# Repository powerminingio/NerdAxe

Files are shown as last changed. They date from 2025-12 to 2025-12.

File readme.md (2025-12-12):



# The Nerdaxe
NerdAxe is a fork from bitaxe with fullcolor display graphics. NerdAxe is indented to be an upgrade board for these who have a NerdMiner and would like to have more powerful mining features without losing the NerdMiner essence. That's why NerdAxe is currently controlled by the common board used on Nerdminer project called TTGO-TDisplayS3.

Currently exists two variants sepparated in two branches:
- **Nerdaxe Gamma**: 1,2Th with a single chip BM1370. [Nerdaxe Gamma](https://github.com/BitMaker-hub/NerdAxe/tree/gamma-1%2C2Ths)
- **Nerdaxe Ultra**: 0,5Th with a single chip BM1366. [Nerdaxe Ultra](https://github.com/BitMaker-hub/NerdAxe/tree/ultra-500Ghs)

The following fork could not be possible without the previous work of @skot, @ben & bitaxe devs. [Check bitaxe project](https://bitaxe.org)

Upgrade your NerdMiner experience throught this addon board and start playing with ASICs

NerdAxeUltra design

## Goals
- **Plug&Play**: your NerdMiner board and convert it into a NerdAxe.
- **Standalone**: can mine directly to your pool over WiFi. No External computer needed.
- **Embedded**: low cost, low maintenance, high availability, high reliability, low power.
- **ASIC**: working with most efficient ASIC chips from Bitmain - BM1370.
- **Versatile**: solo/pool mining, autotune power/heat/efficiency.
- **Open Source**: All design files are provided.

## Features
- **TTGO-TDisplay** ESP32s3 wifi microcontroller display board
- **Multiple Screens** to allow you see all the miner stats 
- **TI TPS546D** buck regulator steps down the 5V input to power the BM1370
- **Microchip EMC2101** PWM controls the fan and monitors tach output. Measuring internal die temp isn't working.

## Additional Features added by Powermining
- **Two fan connectors** - no need for splitter cable if you use secondary fan.
- **Threaded heatsink mounting holes** PCB with M3 threads for firm heatsink mounting
- **OG matching heatsink bolt pattern** no headache with non fitting standard bolt patterns! We keep the Nerdaxe standard 41.49x41.35

## Software & Firmware
Nerdaxe firmware was forked from original ESP-Miner version and adapted to use TTGO board and LVGL as graphic interface lib. 
Check it here -> [ESP-Miner Nerdaxe version](https://github.com/BitMaker-hub/ESP-Miner-NerdAxe)

**Today** Nerdaxe is using the latest evolution of this firmware modified by @pmaxuw (creator of the NerdQaxe) and used for other multiple boards
Current firmware -> [ESP-Miner Nerd\*axe version](https://github.com/shufps/ESP-Miner-NerdQAxePlus)

Flash the latest Nerdaxe firmware here: 
- Go to flasher online tool: https://flasher.bitronics.store/ (recommend via Google Chrome incognito mode)
- Nerd\*axe flasher online tool: https://shufps.github.io/nerdqaxe-web-flasher/  

## The DIY area

### Asic BM1370
- The BM1370 is a undocumented SHA256 mining ASIC from Bitmain. It's mostly used in the Antminer S21pro/S21+
- Bitmain claims the BM1370 has 0.021J/GH efficiency
- The BM1370 is available (new) for around $60 each in small quantities.
- The BM1370 has a different footprint and pinout from the MB1366, BM1368 in previous bitaxe.

### Other components & build troubleshooting
- BM1370 from NBTC on AliExpress
- [40x40mm heatsink and 5V fan](https://www.aliexpress.com/item/2251832861666365.html) from a random AliExpress seller. At least half of these arrived broken in some way. But they are cheap and the working ones do keep the BM1387's nice and cool when used with some thermal compound.
    - Swap this fan with the [Noctua NF-A4x10](https://noctua.at/en/products/fan/nf-a4x10-pwm) 5V 4-Pin fan for a much more pleasant experience.
- Board is designed with [KiCad 8](https://www.kicad.org) design files
- All of the parts on the board are listed in the KiCad BOM
- Check out [building.md](building.md) for PCB ordering tips
- Check out [assembly.md](assembly.md) for assembly tips

### Power Supply Requirements
- 5VDC Power supply 5A minimum. Should be capable of over 25W

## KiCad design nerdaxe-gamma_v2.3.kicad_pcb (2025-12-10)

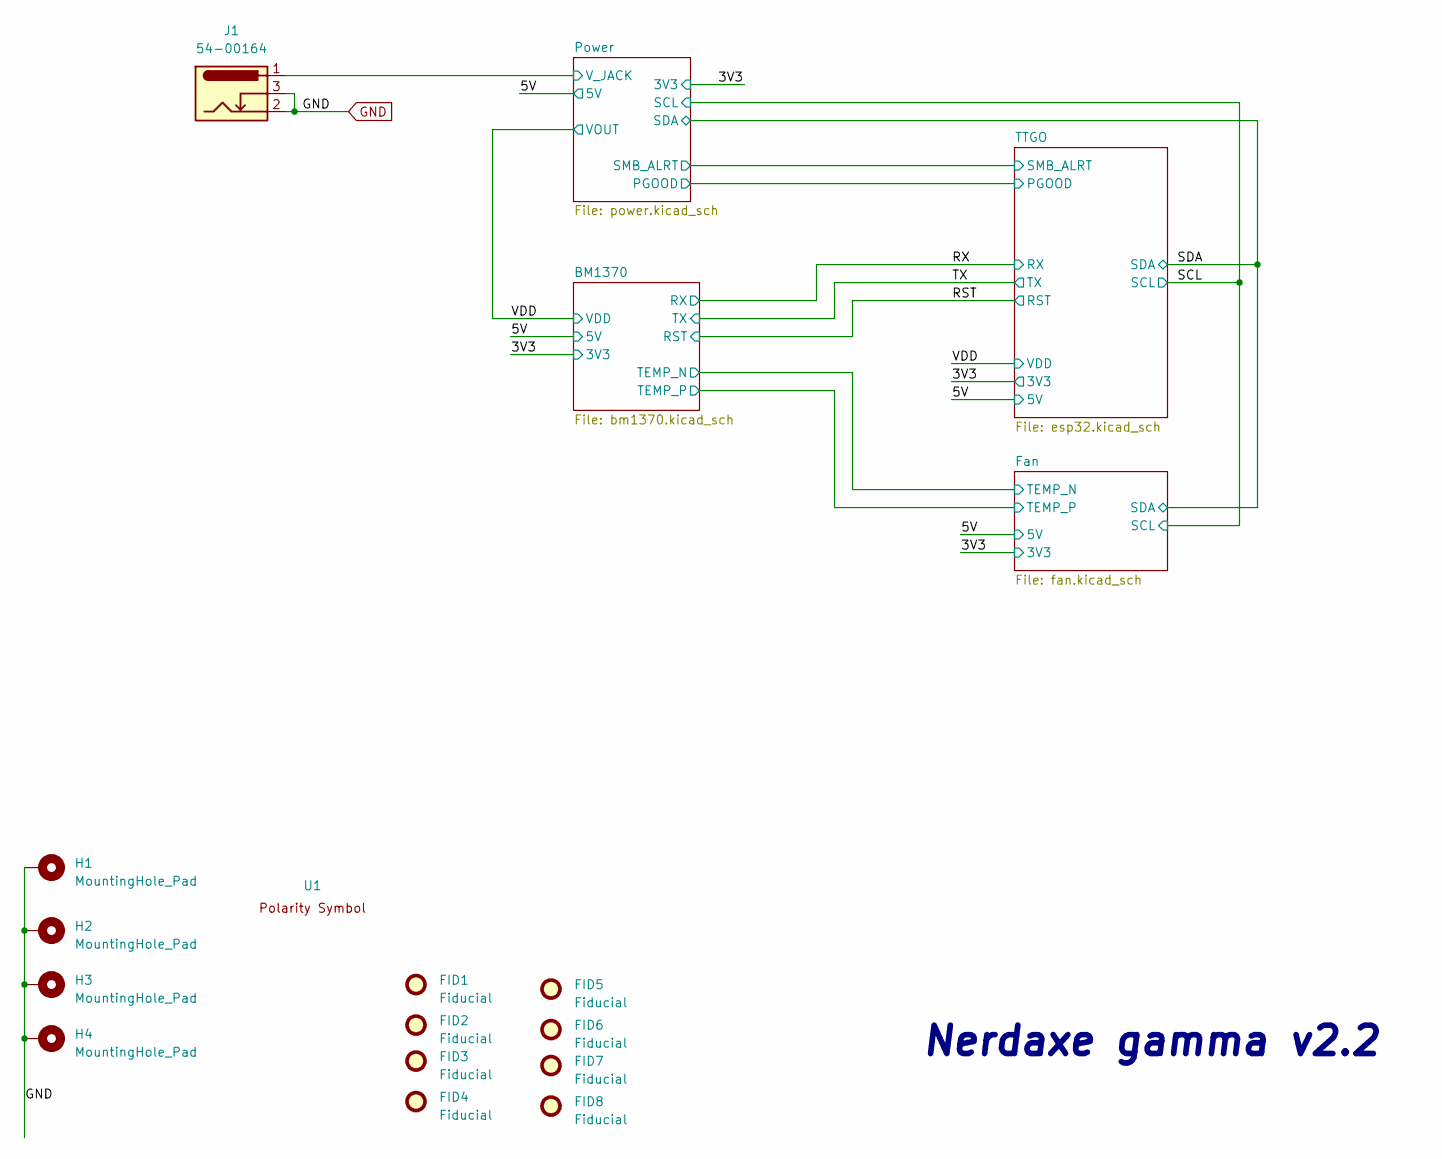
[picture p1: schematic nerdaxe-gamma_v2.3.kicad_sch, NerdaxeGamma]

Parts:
FID1, FID2, FID3, FID4, FID5, FID6, FID7, FID8: Fiducial; Fiducial_1mm_Mask2mm
H1, H2, H3, H4: MountingHole_Pad; MountingHole_3mm_Pad_Via
J1: 54-00164; TENSILITY_54-00164; PARTNO 54-00164; LCSC C431534
U1: polarity

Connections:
/Power/V_JACK: J1.1; also elsewhere on the board
GND: H1.1, H2.1, H3.1, H4.1, J1.2, J1.3; also elsewhere on the board

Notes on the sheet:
Nerdaxe gamma v2.2

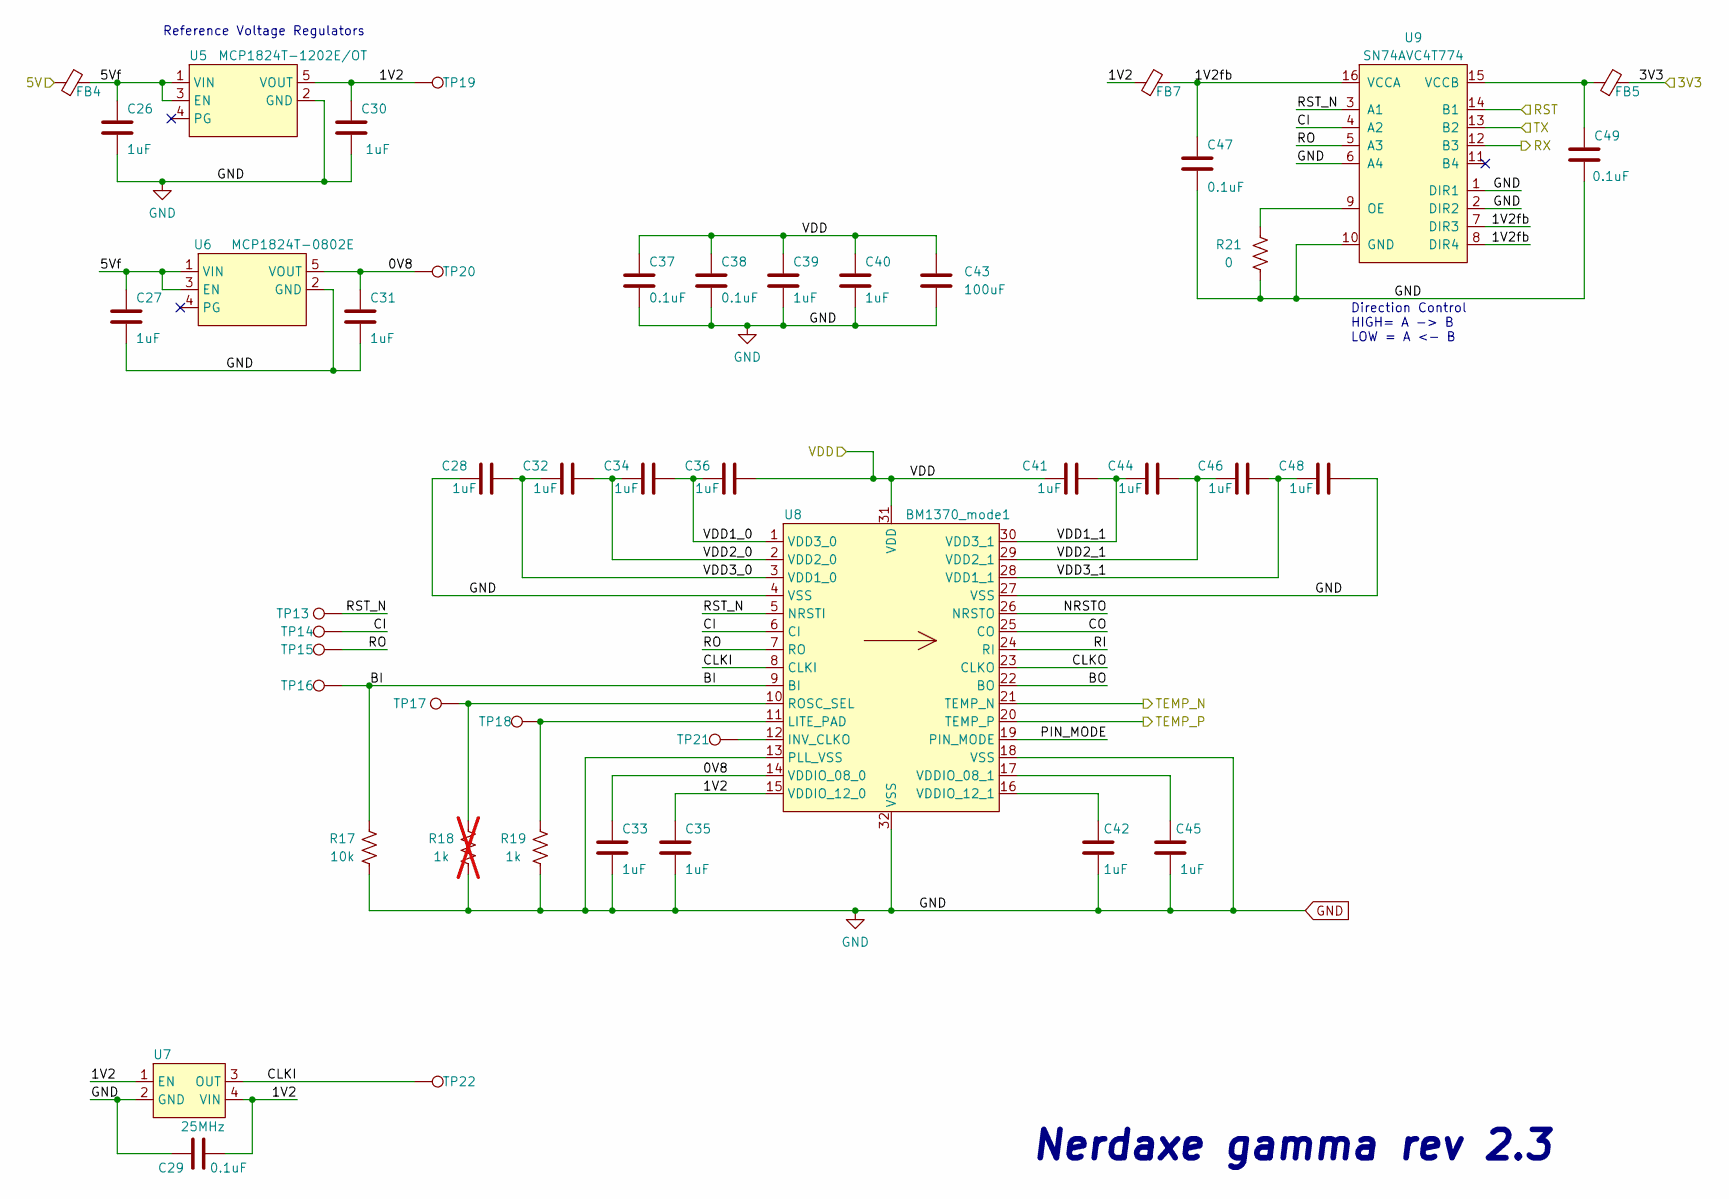
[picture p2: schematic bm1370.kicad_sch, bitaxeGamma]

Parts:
C26, C27, C28, C30, C31, C32, C33, C34, C35, C36, C39, C40, C41, C42, C44, C45, C46, C48: 1uF; C_0402_1005Metric; PARTNO EMK105BJ105MV-F
C29, C37, C38, C47, C49: 0.1uF; C_0402_1005Metric; PARTNO CL05A104KO5NNNC
C43: 100uF; C_1206_3216Metric; PARTNO CL31A107MQHNNNE
FB4, FB5, FB7: BLM21PG221SN1D; R_0805_2012Metric
R17: 10k; R_0402_1005Metric; PARTNO RC0402JR-0710KL
R18: 1k; R_0402_1005Metric; PARTNO RC0402FR-071KL; not fitted
R19: 1k; R_0402_1005Metric; PARTNO RC0402FR-071KL
R21: 0; R_0402_1005Metric; PARTNO RC0402FR-0720KL
TP13, TP14, TP15, TP16, TP17, TP18, TP19, TP20, TP21, TP22: TestPoint; TestPoint_Pad_D1.5mm
U5: MCP1824T-1202E/OT; SOT-23-5; PARTNO MCP1824T-1202E/OT
U6: MCP1824T-0802E; SOT-23-5; PARTNO MCP1824T-0802E/OT
U7: 25MHz; SMD3225-4P; PARTNO SX3M25.000E20F30THN; LCSC C5137262
U8: BM1370_mode1; BM1370
U9: SN74AVC4T774; TSSOP-16_4.4x5mm_P0.65mm; PARTNO SN74AVC4T774PWR

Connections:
/3V3: FB5.2; also elsewhere on the board
/5V: FB4.1; also elsewhere on the board
/BM1370/0V8: C31.1, C33.1, TP20.1, U6.5 (VOUT), U8.14 (VDDIO_08_0)
/BM1370/1V2: C29.2, C30.1, C35.1, FB7.1, TP19.1, U5.5 (VOUT), U7.1 (EN), U7.4 (VIN), U8.15 (VDDIO_12_0)
/BM1370/1V2fb: C47.1, FB7.2, U9.7 (DIR3), U9.8 (DIR4), U9.16 (VCCA)
/BM1370/5Vf: C26.1, C27.1, FB4.2, U5.1 (VIN), U5.3 (EN), U6.1 (VIN), U6.3 (EN)
/BM1370/BI: R17.2, TP16.1, U8.9 (BI)
/BM1370/BO: U8.22 (BO)
/BM1370/CI: TP14.1, U8.6 (CI), U9.4 (A2)
/BM1370/CLKI: TP22.1, U7.3 (OUT), U8.8 (CLKI)
/BM1370/CLKO: U8.23 (CLKO)
/BM1370/CO: U8.25 (CO)
/BM1370/NRSTO: U8.26 (NRSTO)
/BM1370/PIN_MODE: U8.19 (PIN_MODE)
/BM1370/RI: U8.24 (RI)
/BM1370/RO: TP15.1, U8.7 (RO), U9.5 (A3)
/BM1370/RST_N: TP13.1, U8.5 (NRSTI), U9.3 (A1)
/BM1370/VDD1_0: C34.2, C36.1, U8.1 (VDD3_0)
/BM1370/VDD1_1: C41.2, C44.1, U8.30 (VDD3_1)
/BM1370/VDD2_0: C32.2, C34.1, U8.2 (VDD2_0)
/BM1370/VDD2_1: C44.2, C46.1, U8.29 (VDD2_1)
/BM1370/VDD3_0: C28.2, C32.1, U8.3 (VDD1_0)
/BM1370/VDD3_1: C46.2, C48.1, U8.28 (VDD1_1)
/Fan/TEMP_N: U8.21 (TEMP_N); also elsewhere on the board
/Fan/TEMP_P: U8.20 (TEMP_P); also elsewhere on the board
/RST: U9.14 (B1); also elsewhere on the board
/RX: U9.12 (B3); also elsewhere on the board
/TX: U9.13 (B2); also elsewhere on the board
/VDD: C36.2, C37.1, C38.1, C39.1, C40.1, C41.1, C43.1, U8.31 (VDD); also elsewhere on the board
GND: C26.2, C27.2, C28.1, C29.1, C30.2, C31.2, C33.2, C35.2, C37.2, C38.2, C39.2, C40.2, C42.2, C43.2, C45.2, C47.2, C48.2, C49.2, R17.1, R18.1, R19.1, R21.1, U5.2 (GND), U6.2 (GND), U7.2 (GND), U8.4 (VSS), U8.13 (PLL_VSS), U8.18 (VSS), U8.27 (VSS), U8.32 (VSS), U9.1 (DIR1), U9.2 (DIR2), U9.6 (A4), U9.10 (GND); also elsewhere on the board
unnamed: TP21.1, U8.12 (INV_CLKO)
unnamed: R19.2, TP18.1, U8.11 (LITE_PAD)
unnamed: R18.2, TP17.1, U8.10 (ROSC_SEL)
unnamed: C45.1, U8.17 (VDDIO_08_1)
unnamed: C42.1, U8.16 (VDDIO_12_1)
unnamed: R21.2, U9.9 (OE)
unnamed: C49.1, FB5.1, U9.15 (VCCB)

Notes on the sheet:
Reference Voltage Regulators
Direction Control HIGH= A -> B LOW = A <- B
Nerdaxe gamma rev 2.3

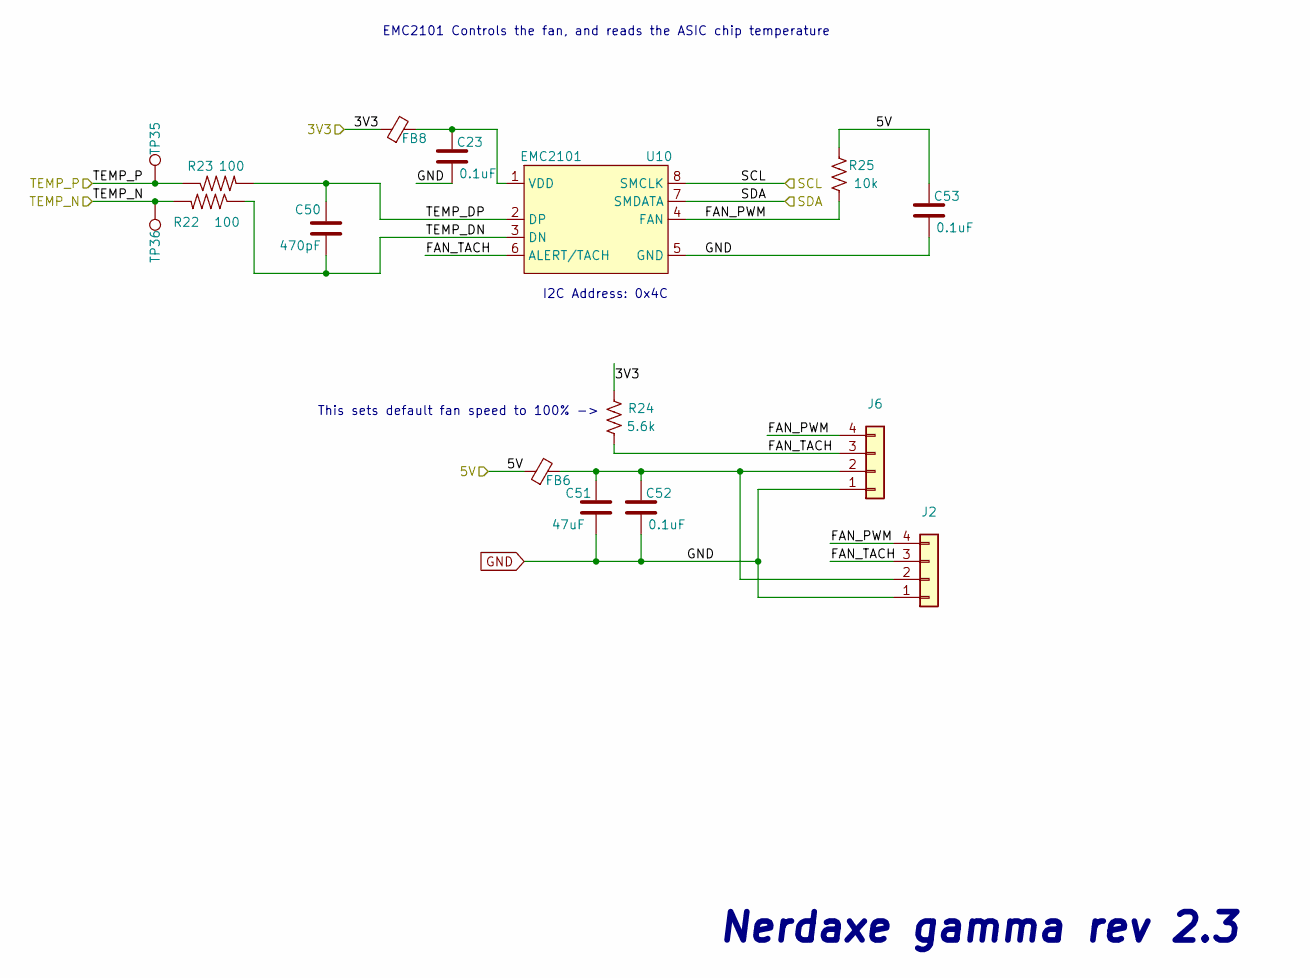
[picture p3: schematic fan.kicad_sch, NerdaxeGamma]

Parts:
C23, C52, C53: 0.1uF; C_0402_1005Metric; PARTNO CL05A104KO5NNNC
C50: 470pF; C_0402_1005Metric; PARTNO CL05B471KB5NNNC
C51: 47uF; C_1210_3225Metric; PARTNO CL32A476KOJNNNE
FB6, FB8: BLM21PG221SN1D; R_0805_2012Metric
J2, J6: Conn_01x04; 470531000; PARTNO 0470531000
R22, R23: 100; R_0402_1005Metric; PARTNO RC0402FR-07100RL
R24: 5.6k; R_0402_1005Metric; PARTNO RC0402FR-135K6L
R25: 10k; R_0402_1005Metric; PARTNO RC0402JR-0710KL
TP35, TP36: TestPoint; TestPoint_Pad_D1.5mm
U10: EMC2101; TSSOP-8_3x3mm_P0.65mm; PARTNO EMC2101-R-ACZL-TR

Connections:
/3V3: FB8.1, R24.2; also elsewhere on the board
/5V: C53.1, FB6.1, R25.2; also elsewhere on the board
/Fan/FAN_PWM: J2.4, J6.4, R25.1, U10.4 (FAN)
/Fan/FAN_TACH: J2.3, J6.3, R24.1, U10.6 (ALERT/TACH)
/Fan/TEMP_DN: C50.2, R22.1, U10.3 (DN)
/Fan/TEMP_DP: C50.1, R23.2, U10.2 (DP)
/Fan/TEMP_N: R22.2, TP36.1; also elsewhere on the board
/Fan/TEMP_P: R23.1, TP35.1; also elsewhere on the board
/SCL: U10.8 (SMCLK); also elsewhere on the board
/SDA: U10.7 (SMDATA); also elsewhere on the board
GND: C23.2, C51.2, C52.2, C53.2, J2.1, J6.1, U10.5 (GND); also elsewhere on the board
unnamed: C51.1, C52.1, FB6.2, J2.2, J6.2
unnamed: C23.1, FB8.2, U10.1 (VDD)

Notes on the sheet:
Nerdaxe gamma rev 2.3
EMC2101 Controls the fan, and reads the ASIC chip temperature
This sets default fan speed to 100% ->
I2C Address: 0x4C

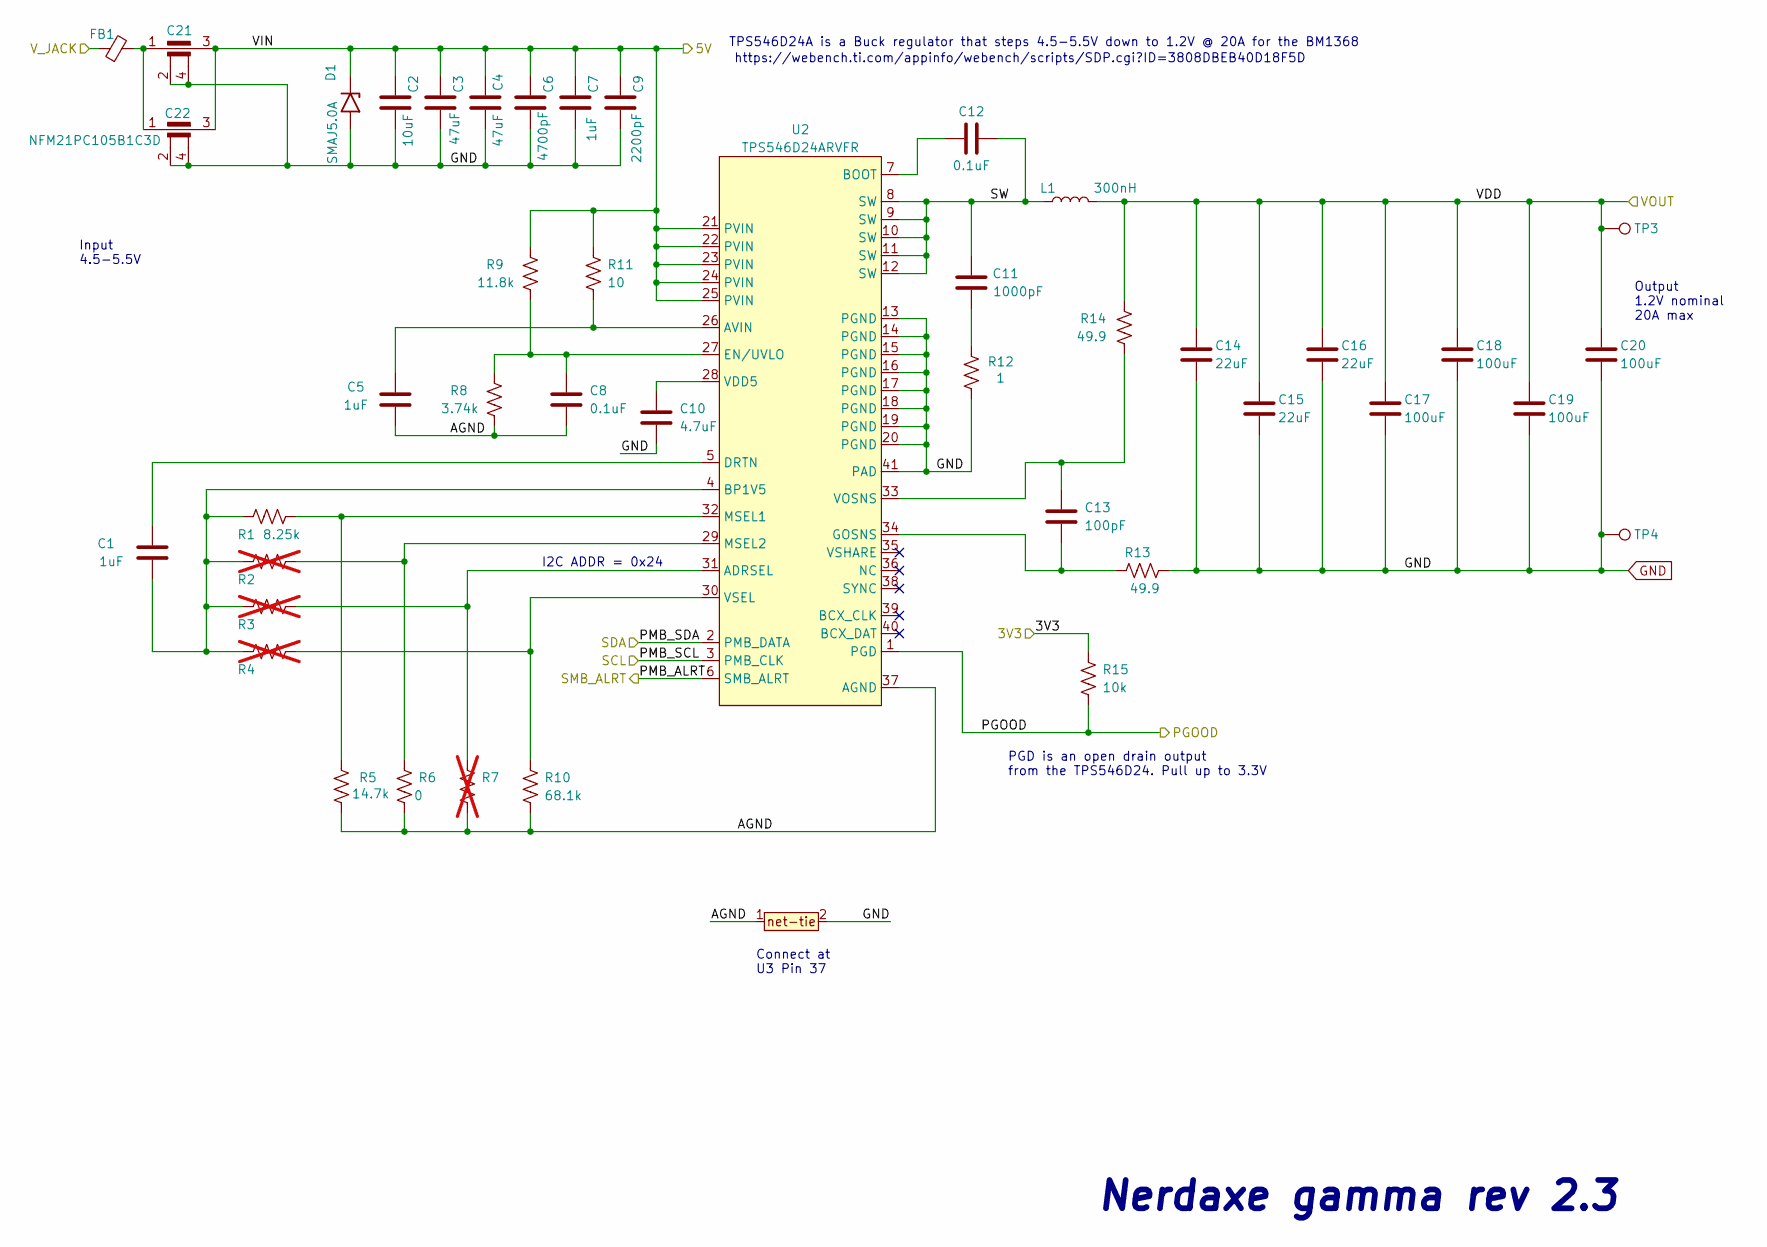
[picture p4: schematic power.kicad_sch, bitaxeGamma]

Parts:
C1, C5, C7: 1uF; C_0402_1005Metric; PARTNO EMK105BJ105MV-F
C2: 10uF; C_0805_2012Metric; PARTNO CL21A106KOQNNNE
C3, C4: 47uF; C_1210_3225Metric; PARTNO CL32A476KOJNNNE
C6: 4700pF; C_0402_1005Metric; PARTNO GRM155R71E472KA01D
C8, C12: 0.1uF; C_0402_1005Metric; PARTNO CL05A104KO5NNNC
C9: 2200pF; C_0402_1005Metric; PARTNO GRM155R61H222KA01D
C10: 4.7uF; C_0402_1005Metric; PARTNO GRM155R61A475MEAAD
C11: 1000pF; C_0805_2012Metric; PARTNO CC0805KRX7R9BB102
C13: 100pF; C_0402_1005Metric; PARTNO 885012005013
C14, C15, C16: 22uF; C_0805_2012Metric; PARTNO GRM21BR61A226ME44L
C17, C18, C19, C20: 100uF; C_1206_3216Metric; PARTNO CL31A107MQHNNNE
C21, C22: NFM21PC105B1C3D; NFM21PC105B1C3D_MUR
D1: SMAJ5.0A; D_SMA
FB1: 2508051217Y6; R_0805_2012Metric
L1: 300nH; SLC1175-271MEC_COC; PARTNO SLC1175-301MEC; Mouser 994-SLC1175-271MEC
R1: 8.25k; R_0402_1005Metric; PARTNO RC0402FR-078K25L
R2, R3, R4, R7: R_0402_1005Metric; not fitted
R5: 14.7k; R_0402_1005Metric; PARTNO RC0402FR-0714K7L
R6: 0; R_0402_1005Metric; PARTNO RC0402JR-070RL
R8: 3.74k; R_0402_1005Metric; PARTNO RC0402FR-073K74L
R9: 11.8k; R_0402_1005Metric; PARTNO RC0402FR-0711K8L
R10: 68.1k; R_0402_1005Metric; PARTNO RC0402FR-0768K1L
R11: 10; R_0402_1005Metric; PARTNO RC0402FR-0710RL
R12: 1; R_1206_3216Metric; PARTNO CSR1206FT1R00
R13, R14: 49.9; R_0402_1005Metric; PARTNO RC0402FR-0749R9L
R15: 10k; R_0402_1005Metric; PARTNO RC0402JR-0710KL
T1: net-tie; NetTie-0.25mm
TP3, TP4: TestPoint; TestPoint_Pad_D1.5mm
U2: TPS546D24ARVFR; LQFN40-CLIP; PARTNO TPS546D24ARVFR

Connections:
/3V3: R15.2; also elsewhere on the board
/5V: C2.1, C3.1, C4.1, C6.1, C7.1, C9.1, C21.3, C22.3, D1.1 (A1), R9.1, R11.1, U2.21 (PVIN), U2.22 (PVIN), U2.23 (PVIN), U2.24 (PVIN), U2.25 (PVIN); also elsewhere on the board
/Power/AGND: C5.1, C8.2, R5.1, R6.2, R7.2, R8.2, R10.2, T1.1, U2.37 (AGND)
/Power/PGOOD: R15.1, U2.1 (PGD); also elsewhere on the board
/Power/PMB_ALRT: U2.6 (SMB_ALRT); also elsewhere on the board
/Power/SW: C11.2, C12.2, L1.1, U2.8 (SW), U2.9 (SW), U2.10 (SW), U2.11 (SW), U2.12 (SW)
/Power/V_JACK: FB1.1; also elsewhere on the board
/SCL: U2.3 (PMB_CLK); also elsewhere on the board
/SDA: U2.2 (PMB_DATA); also elsewhere on the board
/VDD: C14.1, C15.1, C16.1, C17.1, C18.1, C19.1, C20.1, L1.2, R14.1, TP3.1; also elsewhere on the board
GND: C2.2, C3.2, C4.2, C6.2, C7.2, C9.2, C10.2, C14.2, C15.2, C16.2, C17.2, C18.2, C19.2, C20.2, C21.2, C21.4, C22.2, C22.4, D1.2 (A2), R12.1, R13.2, T1.2, TP4.1, U2.13 (PGND), U2.14 (PGND), U2.15 (PGND), U2.16 (PGND), U2.17 (PGND), U2.18 (PGND), U2.19 (PGND), U2.20 (PGND), U2.41 (PAD); also elsewhere on the board
unnamed: C11.1, R12.2
unnamed: C21.1, C22.1, FB1.2
unnamed: R3.2, R7.1, U2.31 (ADRSEL)
unnamed: C5.2, R11.2, U2.26 (AVIN)
unnamed: C12.1, U2.7 (BOOT)
unnamed: C1.2, R1.1, R2.1, R3.1, R4.1, U2.4 (BP1V5)
unnamed: C1.1, U2.5 (DRTN)
unnamed: C8.1, R8.1, R9.2, U2.27 (EN/UVLO)
unnamed: C13.2, R13.1, U2.34 (GOSNS)
unnamed: R1.2, R5.2, U2.32 (MSEL1)
unnamed: R2.2, R6.1, U2.29 (MSEL2)
unnamed: C10.1, U2.28 (VDD5)
unnamed: C13.1, R14.2, U2.33 (VOSNS)
unnamed: R4.2, R10.1, U2.30 (VSEL)

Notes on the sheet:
TPS546D24A is a Buck regulator that steps 4.5-5.5V down to 1.2V @ 20A for the BM1368
https://webench.ti.com/appinfo/webench/scripts/SDP.cgi?ID=3808DBEB40D18F5D
Input 4.5-5.5V
Nerdaxe gamma rev 2.3
PGD is an open drain output from the TPS546D24. Pull up to 3.3V
I2C ADDR = 0x24
Output 1.2V nominal 20A max
Connect at U3 Pin 37

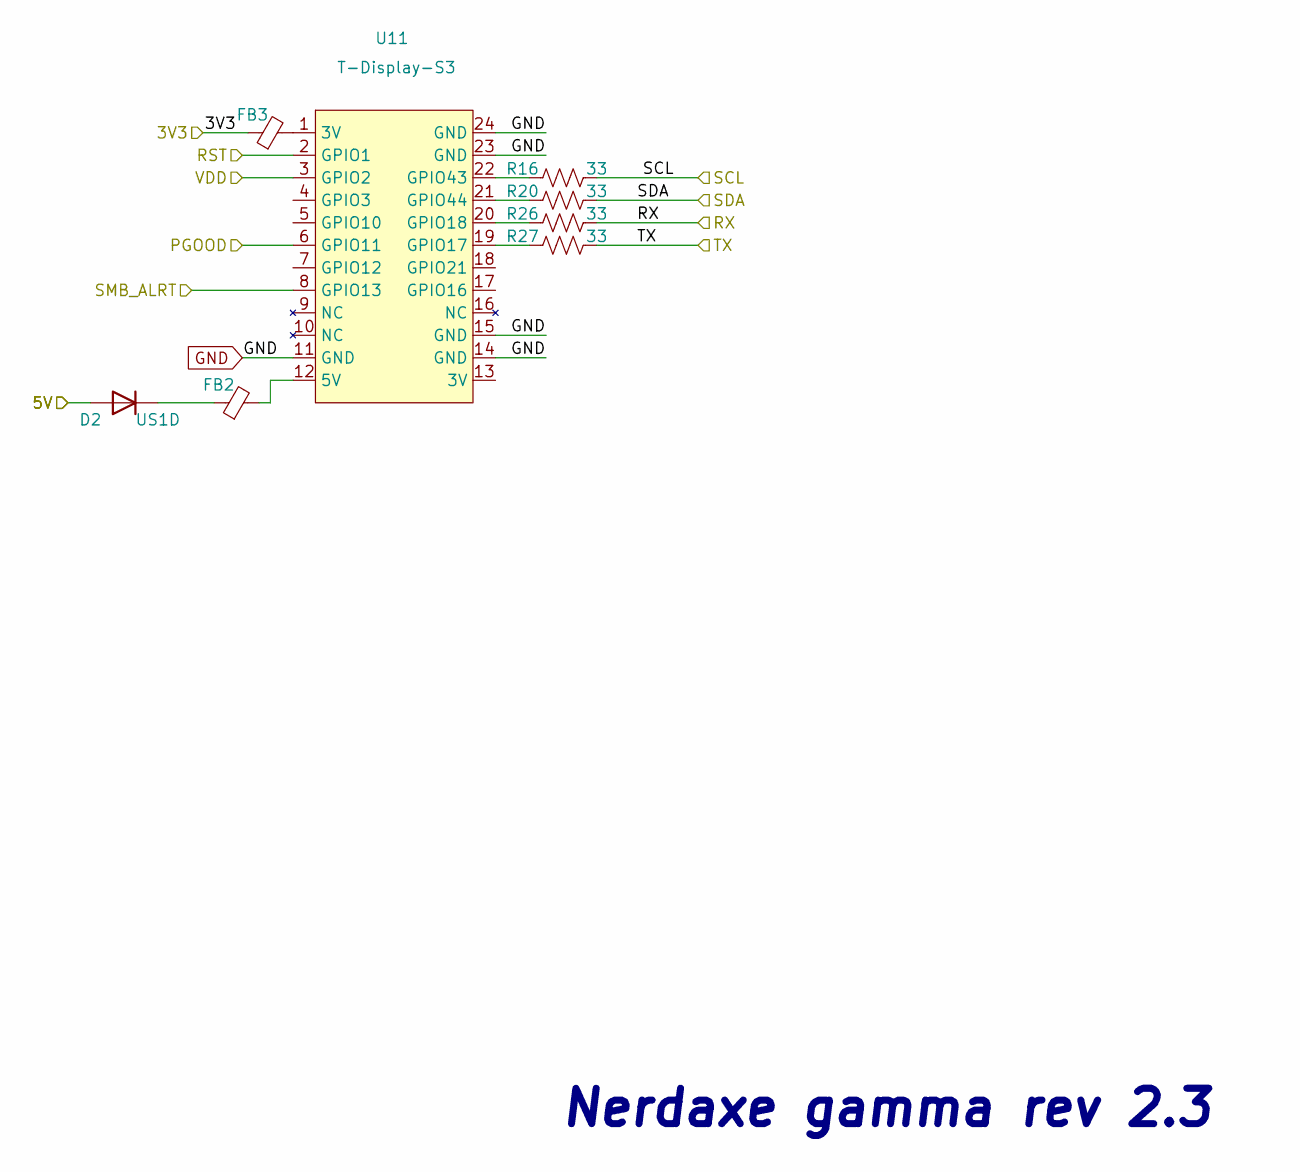
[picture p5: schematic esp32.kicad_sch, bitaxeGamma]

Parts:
D2: US1D; D_SMA
FB2: MPZ2012S221A; R_0805_2012Metric
FB3: BLM21PG221SN1D; R_0805_2012Metric
R16, R20, R26, R27: 33; R_0805_2012Metric; PARTNO RC0402FR-0710RL
U11: T-Display-S3

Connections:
/3V3: FB3.1; also elsewhere on the board
/5V: D2.2 (A); also elsewhere on the board
/Power/PGOOD: U11.6 (GPIO11); also elsewhere on the board
/Power/PMB_ALRT: U11.8 (GPIO13); also elsewhere on the board
/RST: U11.2 (GPIO1); also elsewhere on the board
/RX: R26.2; also elsewhere on the board
/SCL: R16.2; also elsewhere on the board
/SDA: R20.2; also elsewhere on the board
/TX: R27.2; also elsewhere on the board
/VDD: U11.3 (GPIO2); also elsewhere on the board
GND: U11.11 (GND), U11.14 (GND), U11.15 (GND), U11.23 (GND), U11.24 (GND); also elsewhere on the board
unnamed: D2.1 (K), FB2.1
unnamed: FB3.2, U11.1 (3V)
unnamed: FB2.2, U11.12 (5V)
unnamed: R27.1, U11.19 (GPIO17)
unnamed: R26.1, U11.20 (GPIO18)
unnamed: R16.1, U11.22 (GPIO43)
unnamed: R20.1, U11.21 (GPIO44)

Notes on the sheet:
Nerdaxe gamma rev 2.3

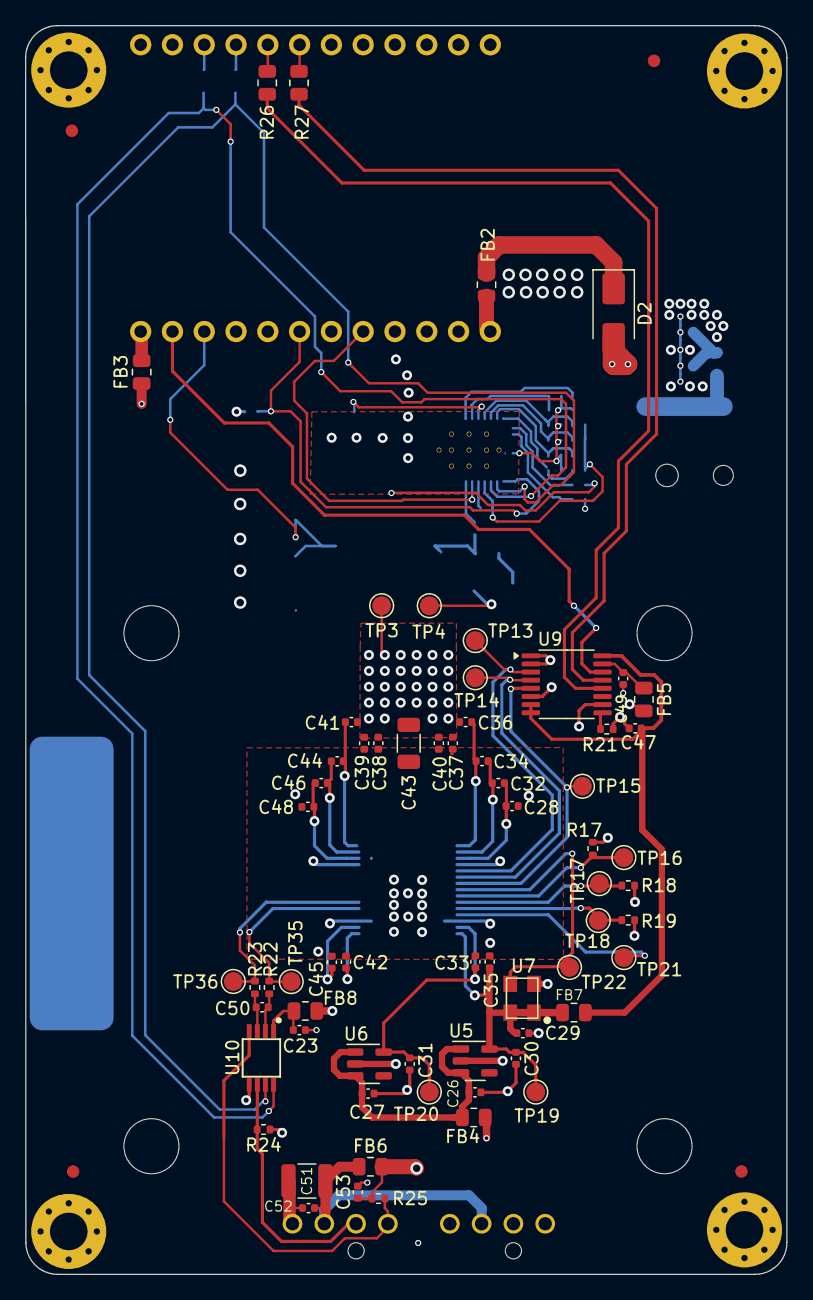
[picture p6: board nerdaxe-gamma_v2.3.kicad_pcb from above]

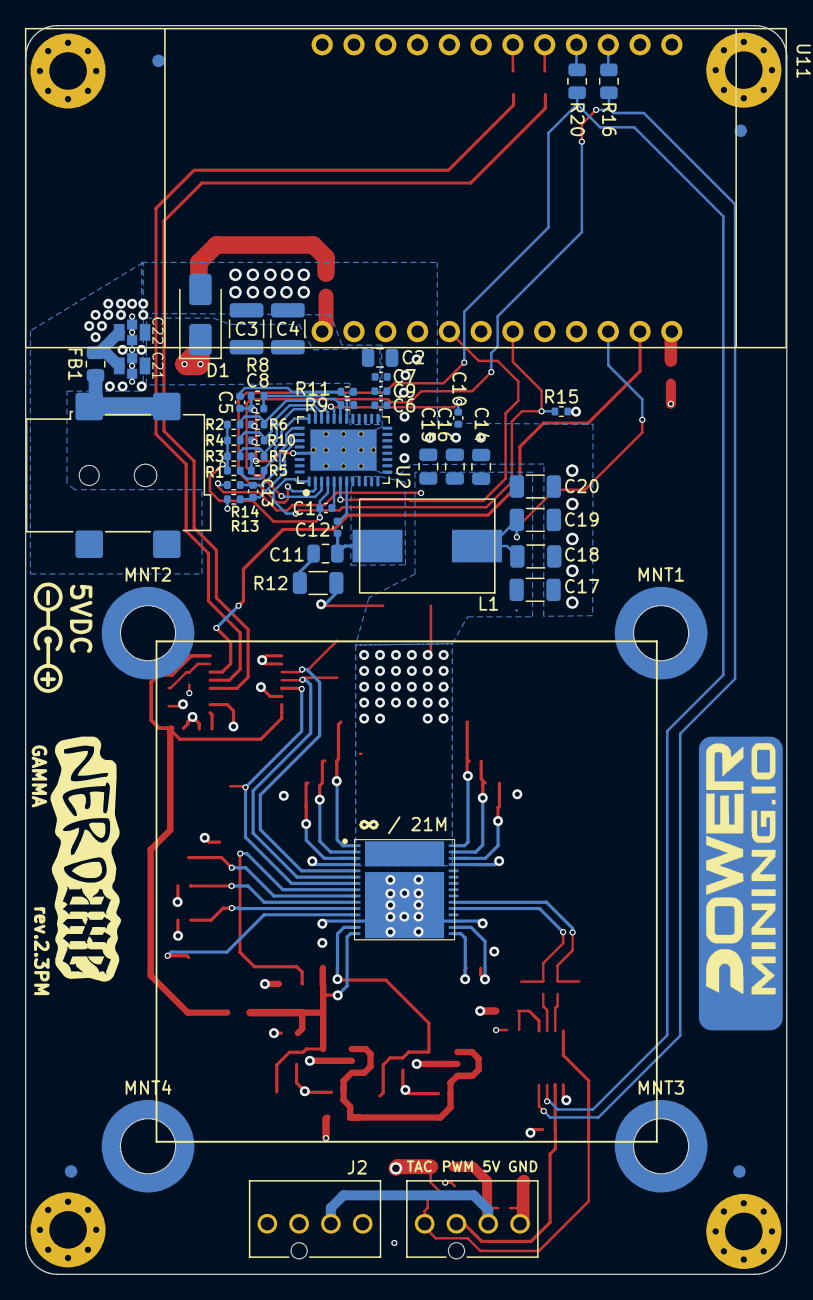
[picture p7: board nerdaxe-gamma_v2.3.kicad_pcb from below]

Board: 4 copper layers, 60.8 x 99.8 mm, 132 parts (58 on the bottom side), 65 nets.

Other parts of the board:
MNT1, MNT2, MNT3, MNT4: Mounting_Wuerth_WA-SMSI-M3_H0.5mm_9774005360

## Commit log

2025-12-10 Powermining upgrades
    [bm1370.kicad_sch, esp32.kicad_sch, fan.kicad_sch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]
2025-12-12 Corrected device name in readme
